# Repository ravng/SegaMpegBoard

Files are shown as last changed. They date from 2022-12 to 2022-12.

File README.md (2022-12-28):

# SegaMpegBoard!
board Mpeg Replacement

Drop in replacement board for Sega Model 3 Mpeg board.
Tested on Scud Race but can't see why it would not work in other aracdes with the same mpeg board.

It uses the cheap DFPlayer MP3 module for soundtrack files and attiny84 for the communication.

A jumper is used to select different soundtracks (folders). 
Folder 1-4 plays the same sound track for each race track every time, while folder 5 will play songs in random order. 
If no jumper installed it will use folder "01", see source for details. 

IMPORTANT NOTE!
The attiny might need a clock calibration to work. 
I supposed it would be smart to add an external clock, but I didn't.
Fell free to modify the design yourself or search the web for attiny clock calibration.

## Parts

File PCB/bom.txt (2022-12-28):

Sega Mpeg Board BOM

C1:	10uF Capacitor polarized	
C2:	0.1uF Capacitor
LED1:	Any color led
R1:	10k *
R2:	220R
R3:	220R
R4:	220R
R5:	220R
R6:	1k
R7:	1k
R8:	10k *
IC1:	Attiny84 
IC2:	6N138 Opto Isolator
IC3:  DFPlayer module (suggest female header pins)
All connectors:	2.54mm Male Header pins

*(will most likely work perfectly fine without!)

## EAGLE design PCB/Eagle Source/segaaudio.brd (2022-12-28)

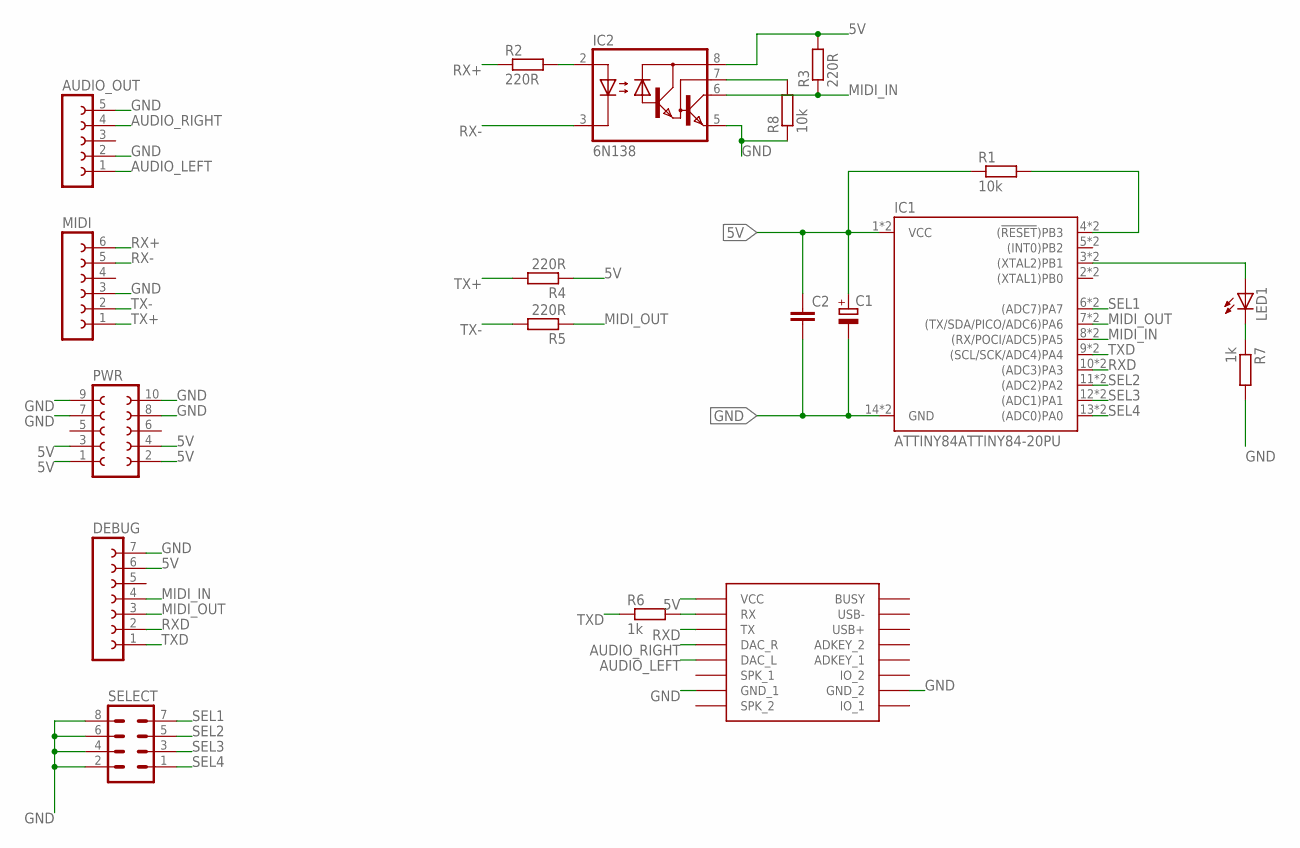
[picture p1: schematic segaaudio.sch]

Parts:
AUDIO_OUT: FE05-1
C1: CPOL-EUE5-10.5; E5-10,5
C2: C-EU050-025X075; C050-025X075
DEBUG: FE07-1; FE07
IC1: ATTINY84ATTINY84-20PU; DIP14
IC2: 6N138; DIL08
IC3: DFPLAYER
LED1: LED3MM
MIDI: FE06-1; FE06
PWR: FE05-2
R1, R8: 10k; 0309/12
R2, R3, R4, R5: 220R; 0309/12
R6, R7: 1k; 0309/12
SELECT: MA04-2

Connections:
5V: C1.+, C2.1, DEBUG.6, IC1.1 (VCC), IC1.1A (VCC), IC2.8 (VCC), IC3.VCC, PWR.1, PWR.2, PWR.3, PWR.4, R1.1, R3.2, R4.1
AUDIO_LEFT: AUDIO_OUT.1, IC3.DAC_L
AUDIO_RIGHT: AUDIO_OUT.4, IC3.DAC_R
GND: AUDIO_OUT.2, AUDIO_OUT.5, C1.-, C2.2, DEBUG.7, IC1.14 (GND), IC1.14A (GND), IC2.5 (GND), IC3.GND_1, IC3.GND_2, MIDI.3, PWR.7, PWR.8, PWR.9, PWR.10, R7.2, R8.1, SELECT.2, SELECT.4, SELECT.6, SELECT.8
MIDI_IN: DEBUG.4, IC1.8 ((RX/POCI/ADC5)PA5), IC1.8A ((RX/POCI/ADC5)PA5), IC2.6 (VO), R3.1
MIDI_OUT: DEBUG.3, IC1.7 ((TX/SDA/PICO/ADC6)PA6), IC1.7A ((TX/SDA/PICO/ADC6)PA6), R5.1
unnamed: IC1.4 ((!RESET!)PB3), IC1.4A ((!RESET!)PB3), R1.2
unnamed: IC2.2 (A), R2.2
unnamed: IC1.3 ((XTAL2)PB1), IC1.3A ((XTAL2)PB1), LED1.A
unnamed: LED1.K (C), R7.1
unnamed: IC3.RX, R6.2
unnamed: IC2.7 (VB), R8.2
RX+: MIDI.6, R2.1
RX-: IC2.3 (C), MIDI.5
RXD: DEBUG.2, IC1.10 ((ADC3)PA3), IC1.10A ((ADC3)PA3), IC3.TX
SEL1: IC1.6 ((ADC7)PA7), IC1.6A ((ADC7)PA7), SELECT.7
SEL2: IC1.11 ((ADC2)PA2), IC1.11A ((ADC2)PA2), SELECT.5
SEL3: IC1.12 ((ADC1)PA1), IC1.12A ((ADC1)PA1), SELECT.3
SEL4: IC1.13 ((ADC0)PA0), IC1.13A ((ADC0)PA0), SELECT.1
TX+: MIDI.1, R4.2
TX-: MIDI.2, R5.2
TXD: DEBUG.1, IC1.9 ((SCL/SCK/ADC4)PA4), IC1.9A ((SCL/SCK/ADC4)PA4), R6.1

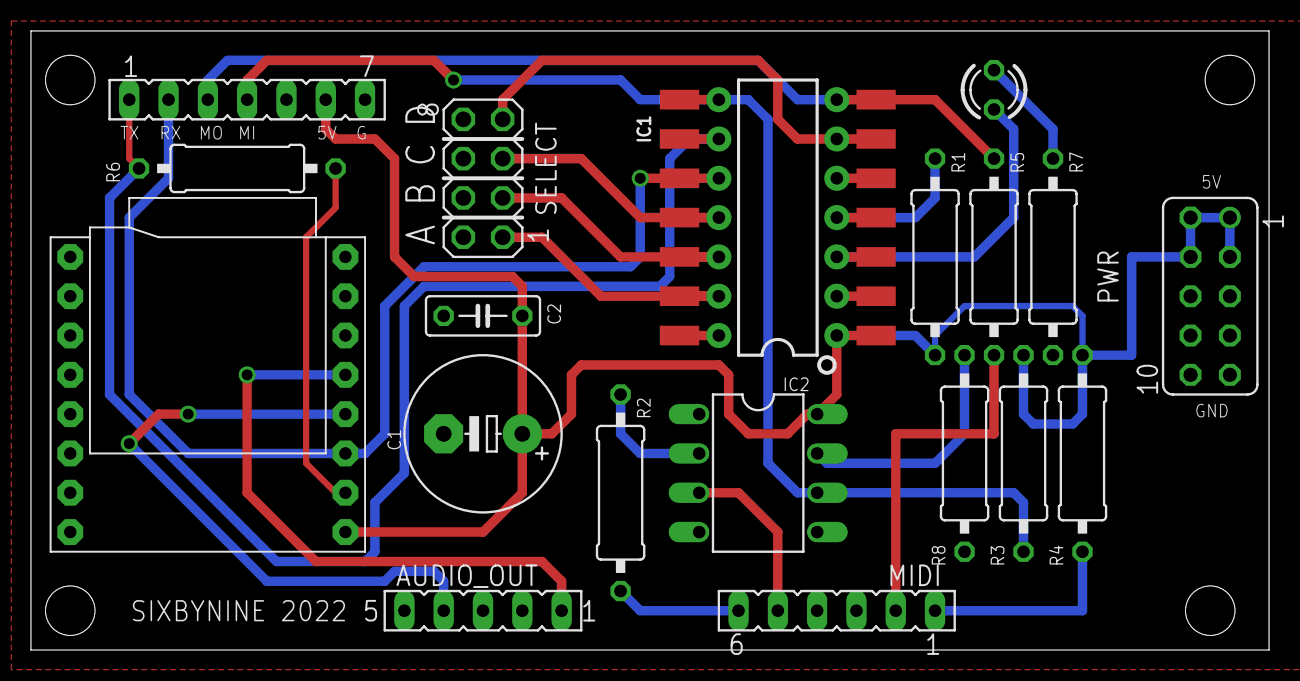
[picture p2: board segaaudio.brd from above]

Board: 2 copper layers, 80.0 x 40.0 mm, 19 parts (0 on the bottom side), 22 nets.

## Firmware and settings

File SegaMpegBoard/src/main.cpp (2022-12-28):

#include <Arduino.h>
/*
Sega Mpeg Board emulator
By Sixbynine 2022

Tracks:
Filename  Use
01/001.mp3     Medium Track
01/002.mp3     Beginner Night
01/003.mp3     Beginner Day
01/004.mp3     Extra
01/005.mp3     Expert
01/006.mp3     Selector 
01/007.mp3     Name entry 
01/008.mp3     Goal
01/009.mp3     Ending
01/010.mp3     Intro/Attract
*/

// DFMini setup
#include <SoftwareSerial.h>
#include "DFRobotDFPlayerMini.h"
#include <EEPROM.h>
SoftwareSerial mp3serial(7,6);
SoftwareSerial midiserial(5,4);
DFRobotDFPlayerMini myDFPlayer;

// HW setup
#define led 1
#define selectA 3
#define selectB 8
#define selectC 9
#define selectD 10

// Globals
byte mididata[3];
unsigned int c=0;
unsigned int folder=0;
unsigned int trackplaying=0;
unsigned long ts=millis();

unsigned int getfolder() {
  // Get jumper settings for folder to play
  int sA = digitalRead(selectA);
  int sB = digitalRead(selectB);
  int sC = digitalRead(selectC);
  int sD = digitalRead(selectD);
  if ( sA == 1 and sB == 1 and sC == 1 and sD == 1 )
    return(1);
  if ( sA == 0 and sB == 1 and sC == 1 and sD == 1 )
    return(2);
  if ( sA == 1 and sB == 0 and sC == 1 and sD == 1 )
    return(3);
  if ( sA == 1 and sB == 1 and sC == 0 and sD == 1 )
    return(4);
  if ( sA == 1 and sB == 1 and sC == 1 and sD == 0 )
    return(5);
  return(1);  
}

void blinkled(int num) {
    for ( int i=0; i < num; i++ ) {
      digitalWrite(led, HIGH);
      delay(200);
      digitalWrite(led, LOW);
      delay(200);
    }
}
void playtrack(byte track) {
  if ( track == 0 )
    track=10;
  mp3serial.listen(); 
  if ( trackplaying != track ) {
    myDFPlayer.playFolder(folder, track);  
  }
  trackplaying=track;
  midiserial.listen();
}

void stoptrack() {
  mp3serial.listen();
  myDFPlayer.pause();
  trackplaying=0;
  midiserial.listen();
}

void setup() {
  // Tune cpu
  byte T = EEPROM.read(0);
  OSCCAL = T;
  midiserial.begin(31250);              
  mp3serial.begin(9600);            
  pinMode(led, OUTPUT);             
  digitalWrite(led, LOW);
  pinMode(selectA, INPUT_PULLUP);
  pinMode(selectB, INPUT_PULLUP);
  pinMode(selectC, INPUT_PULLUP);
  pinMode(selectD, INPUT_PULLUP);
  folder=getfolder();
  blinkled(folder);
  mp3serial.listen();
  myDFPlayer.begin(mp3serial);
  myDFPlayer.volume(20);
  myDFPlayer.enableLoop();
}

void loop() {
  // Check for Midi data
  midiserial.listen();
  if ( midiserial.available() ) {
      // Capture 3 bytes
      byte indata = midiserial.read();
      if ( indata == 0xAF )
        c=0;
      mididata[c++] = indata;
      if ( c == 3 ) {
        // Parse midi data
        if ( mididata[0] == 0xAF and mididata[1] == 0x6F ) {  // Song command
          if ( folder != 5 )
            playtrack(mididata[2]);
          else {
           playtrack(random(1,10));
          }
        }
        if ( mididata[0] == 0xAF and mididata[1] == 0x3 and mididata[2] == 0x18 ) {  // Stop command
          stoptrack();
        }
        c=0;         
      }
  }
}

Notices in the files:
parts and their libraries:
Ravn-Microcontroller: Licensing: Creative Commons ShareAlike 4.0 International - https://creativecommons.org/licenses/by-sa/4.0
